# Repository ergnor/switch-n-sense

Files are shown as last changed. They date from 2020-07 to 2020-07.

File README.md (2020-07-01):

# Switch-N-Sense
This is a Kicad redesign of switch-n-sense pcb from LibreSolar project

## Design changes:

* Wire to board connector is replaced with cheaper alternative - Keystone 8197 (30A rating)
* MOSFET's footprint now is TDSON-8-1 for 5x6 mm SMD transistors 
* Pinout of connector to the BMS (IDC connector) is compatible with previous version of pcb
* C1,C2,C6 and C7 are changed to 0805(2012) size

## Current target

Current rating can be adjusted depending on chosen MOSFETs and sense resistors, but major limiting factor is connector (30A)

| MOSFET (2x) | Voltage | Maximum Current | Remark |
|---|---|---|---|
|NVMFS6H800NT1G | 48V | 30 A | connector limited |

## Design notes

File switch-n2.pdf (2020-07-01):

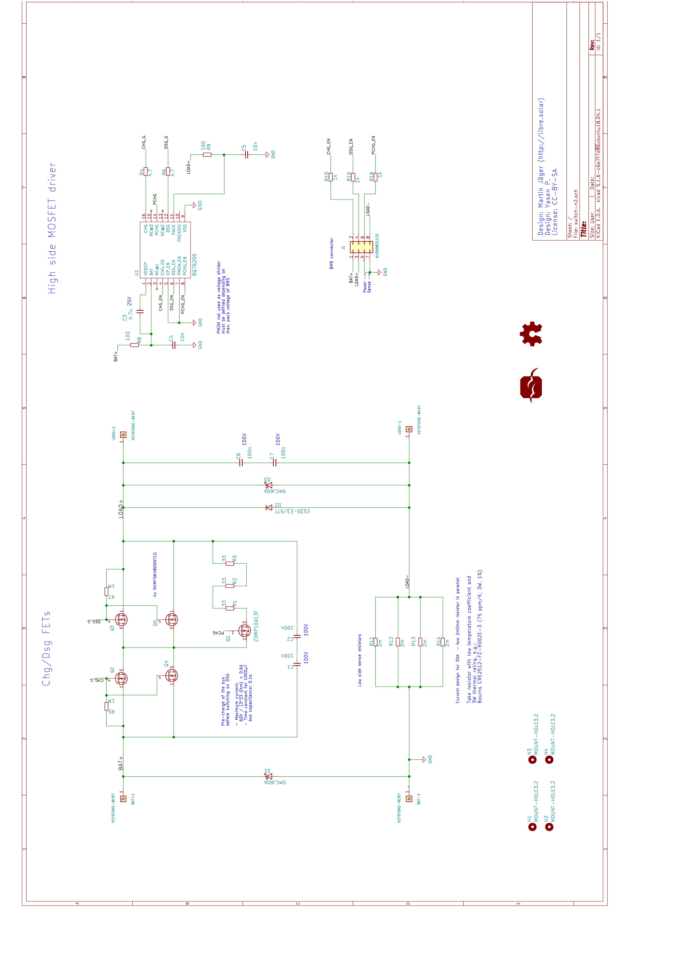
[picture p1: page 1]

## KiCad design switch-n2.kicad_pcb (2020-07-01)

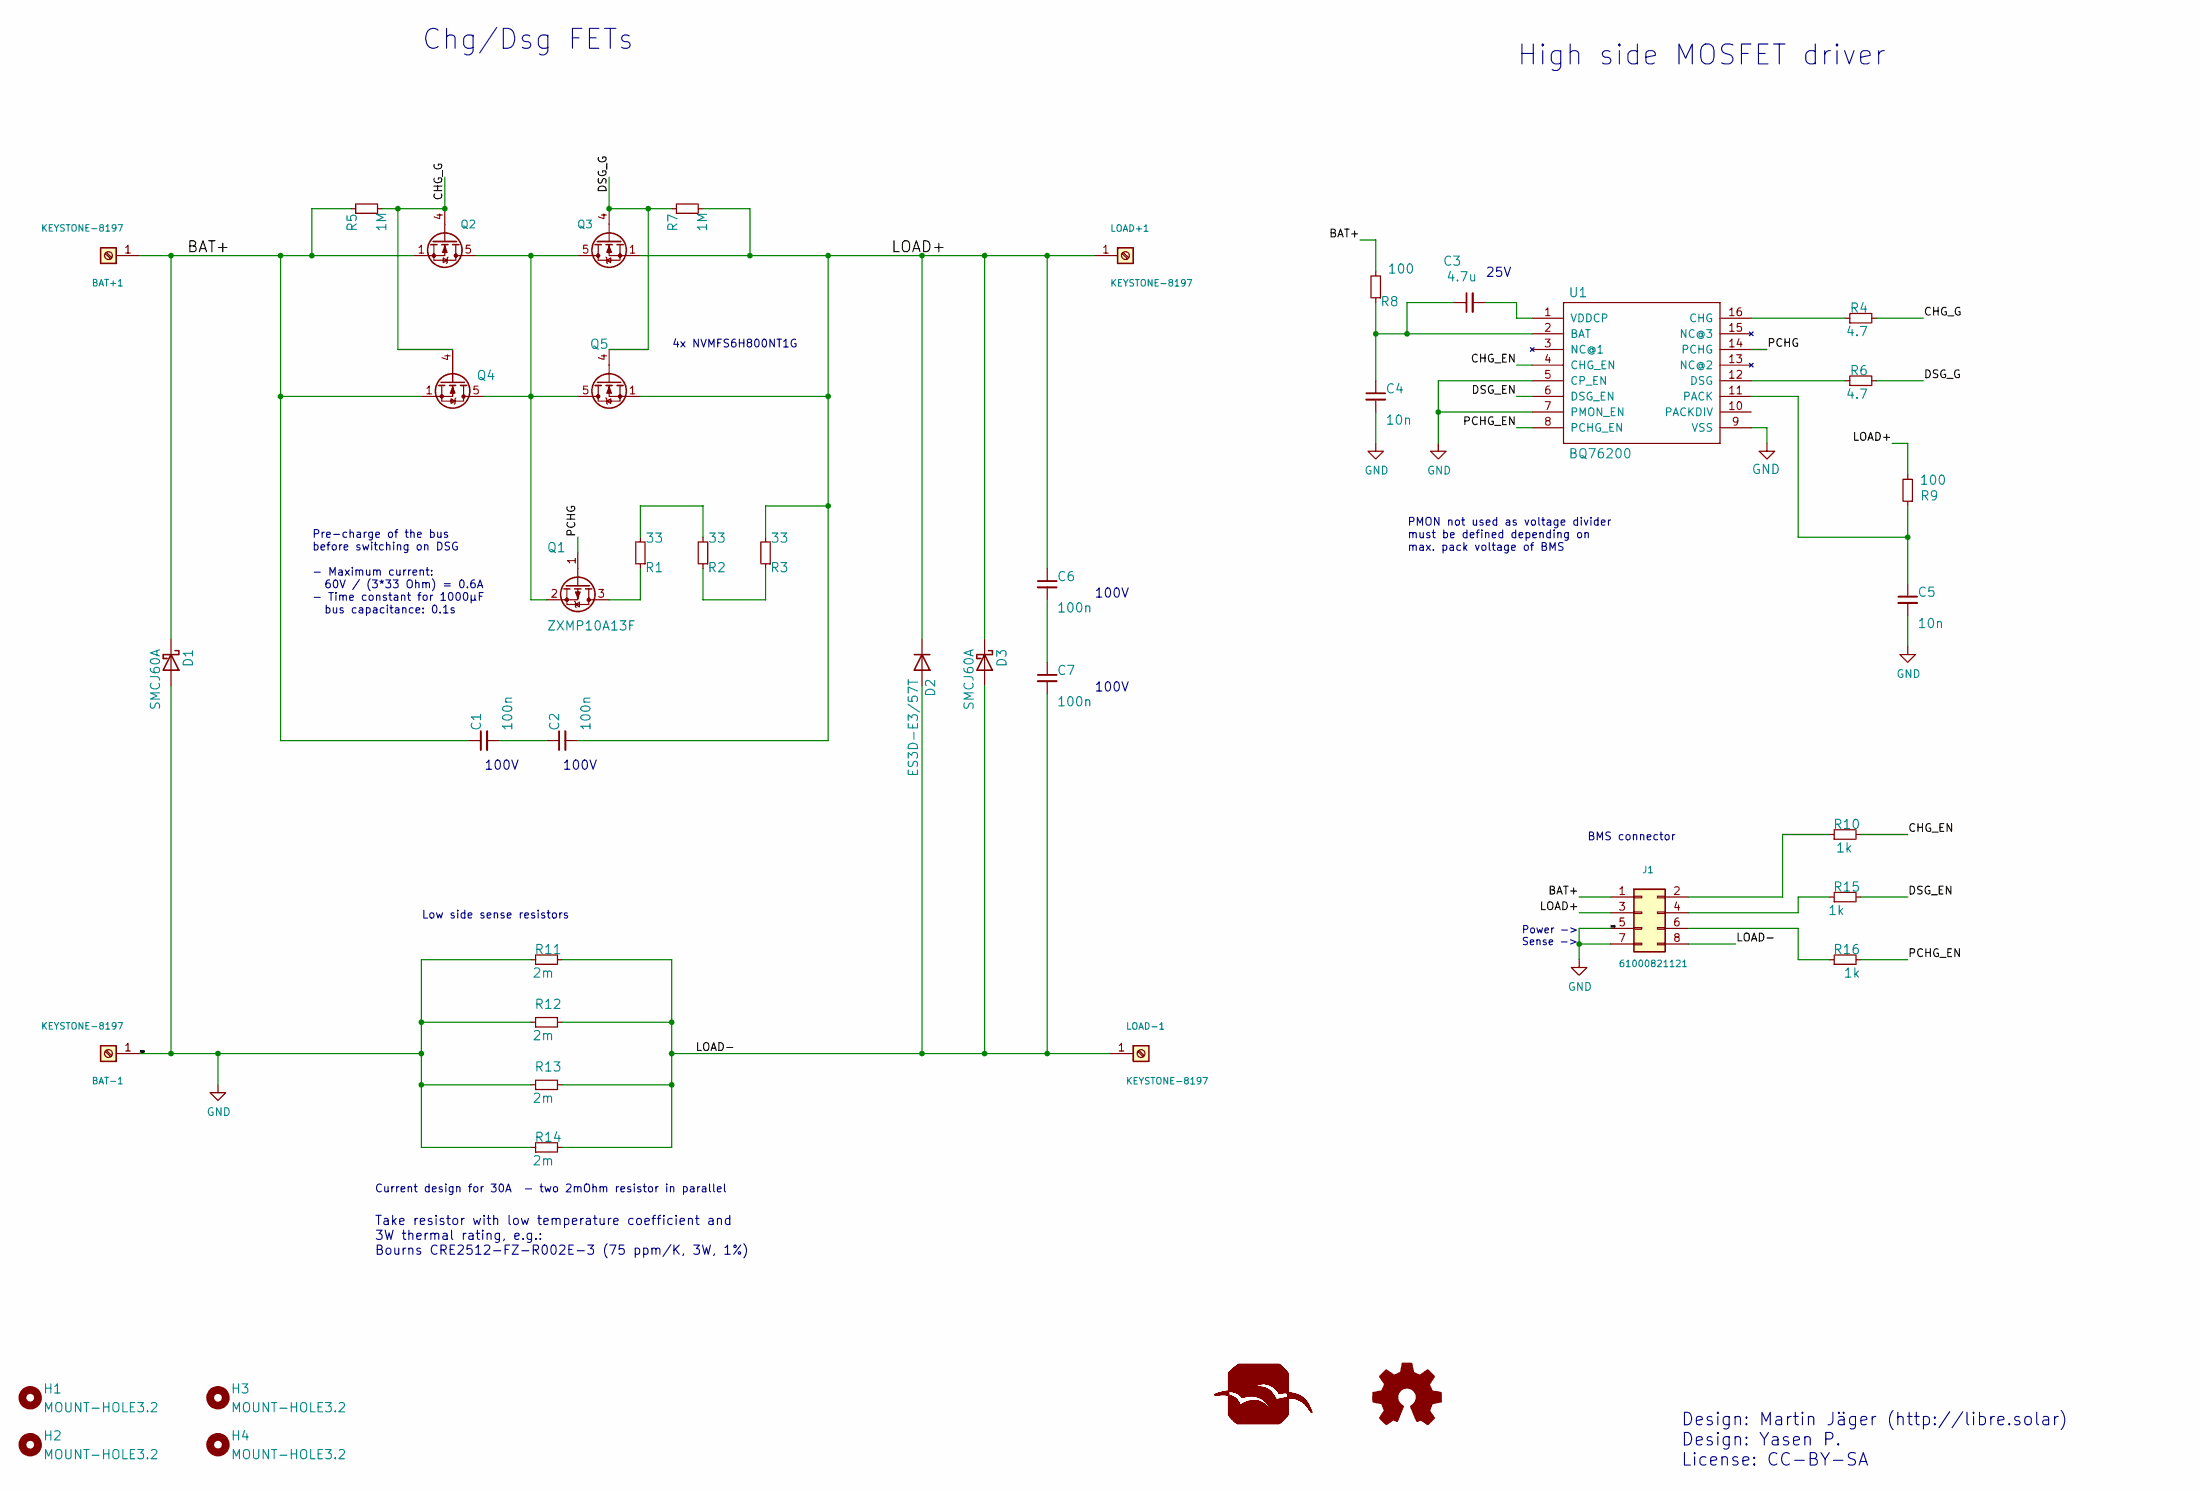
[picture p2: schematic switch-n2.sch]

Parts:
BAT+1: KEYSTONE-8197; 8197
BAT-1: KEYSTONE-8197; 8197
C1, C2, C6, C7: 100n; C_0805_2012Metric; MPN 0603B104K500CT
C3: 4.7u; C_0805_2012Metric; MPN 0603B104K500CT
C4, C5: 10n; C_0603_1608Metric; MPN GRM188R71H103KA01D.
D1, D3: SMCJ60A; D_SMC; MPN SMCJ75A
D2: ES3D-E3/57T; D_SMC; MPN ES3D-E3/57T.
H1, H2, H3, H4: MOUNT-HOLE3.2; MountingHole_3.2mm_M3_ISO14580_Pad
J1: 61000821121; PinHeader_2x04_P2.54mm_Vertical_SMD
LOAD+1: KEYSTONE-8197; 8197
LOAD-1: KEYSTONE-8197; 8197
N1: OSHW-LOGOM; OSHW-LOGO-M
Q1: ZXMP10A13F; SOT-23; MPN ZXMP10A13FTA
Q2, Q3, Q4, Q5: NVMFS6H800NT1G; TDSON-8-1
R1, R2, R3: 33; R_2010_5025Metric; MPN ASC2010-33RFT4
R4, R6: 4.7; R_0603_1608Metric; MPN ERJU06F1004V
R5, R7: 1M; R_0603_1608Metric; MPN ERJU06F1004V
R8, R9: 100; R_0603_1608Metric; MPN MCMR06X1001FTL
R10, R15, R16: 1k; R_0603_1608Metric; MPN ERJU06F1004V
R11, R12, R13, R14: 2m; R_2512_6332Metric
U1: BQ76200; TSSOP16
U$1: LIBRESOLAR_LOGO

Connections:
/BAT+: BAT+1.1, C1.1, D1.1 (K), J1.1, Q2.1 (S), Q2.2 (S), Q2.3 (S), Q4.1 (S), Q4.2 (S), Q4.3 (S), R5.1, R8.2
/CHG_EN: R10.2, U1.4 (CHG_EN)
/CHG_G: Q2.4 (G), Q4.4 (G), R4.2, R5.2
/DSG_EN: R15.2, U1.6 (DSG_EN)
/DSG_G: Q3.4 (G), Q5.4 (G), R6.2, R7.1
/LOAD+: C2.2, C6.1, D2.1 (K), D3.1 (K), J1.3, LOAD+1.1, Q3.1 (S), Q3.2 (S), Q3.3 (S), Q5.1 (S), Q5.2 (S), Q5.3 (S), R3.2, R7.2, R9.2
/LOAD-: C7.2, D2.2 (A), D3.2 (A), J1.8, LOAD-1.1, R11.2, R12.2, R13.2, R14.2
/PCHG: Q1.1 (G), U1.14 (PCHG)
/PCHG_EN: R16.2, U1.8 (PCHG_EN)
GND: BAT-1.1, C4.2, C5.2, D1.2 (A), J1.5, J1.7, R11.1, R12.1, R13.1, R14.1, U1.5 (CP_EN), U1.7 (PMON_EN), U1.9 (VSS)
unnamed: C1.2, C2.1
unnamed: C3.1, C4.1, R8.1, U1.2 (BAT)
unnamed: C3.2, U1.1 (VDDCP)
unnamed: C5.1, R9.1, U1.11 (PACK)
unnamed: C6.2, C7.1
unnamed: J1.2, R10.1
unnamed: J1.4, R15.1
unnamed: J1.6, R16.1
unnamed: Q1.2 (S), Q2.5 (D), Q3.5 (D), Q4.5 (D), Q5.5 (D)
unnamed: Q1.3 (D), R1.1
unnamed: R1.2, R2.2
unnamed: R2.1, R3.1
unnamed: R4.1, U1.16 (CHG)
unnamed: R6.1, U1.12 (DSG)

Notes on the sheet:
Pre-charge of the bus before switching on DSG - Maximum current: 60V / (3*33 Ohm) = 0.6A - Time constant for 1000µF bus capacitance: 0.1s
Chg/Dsg FETs
High side MOSFET driver
Design: Martin Jäger (http://libre.solar) Design: Yasen P. License: CC-BY-SA
4x NVMFS6H800NT1G
Take resistor with low temperature coefficient and 3W thermal rating, e.g.: Bourns CRE2512-FZ-R002E-3 (75 ppm/K, 3W, 1%)
Low side sense resistors
BMS connector
Power -> Sense ->
PMON not used as voltage divider must be defined depending on max. pack voltage of BMS
100V
25V
Current design for 30A - two 2mOhm resistor in parallel

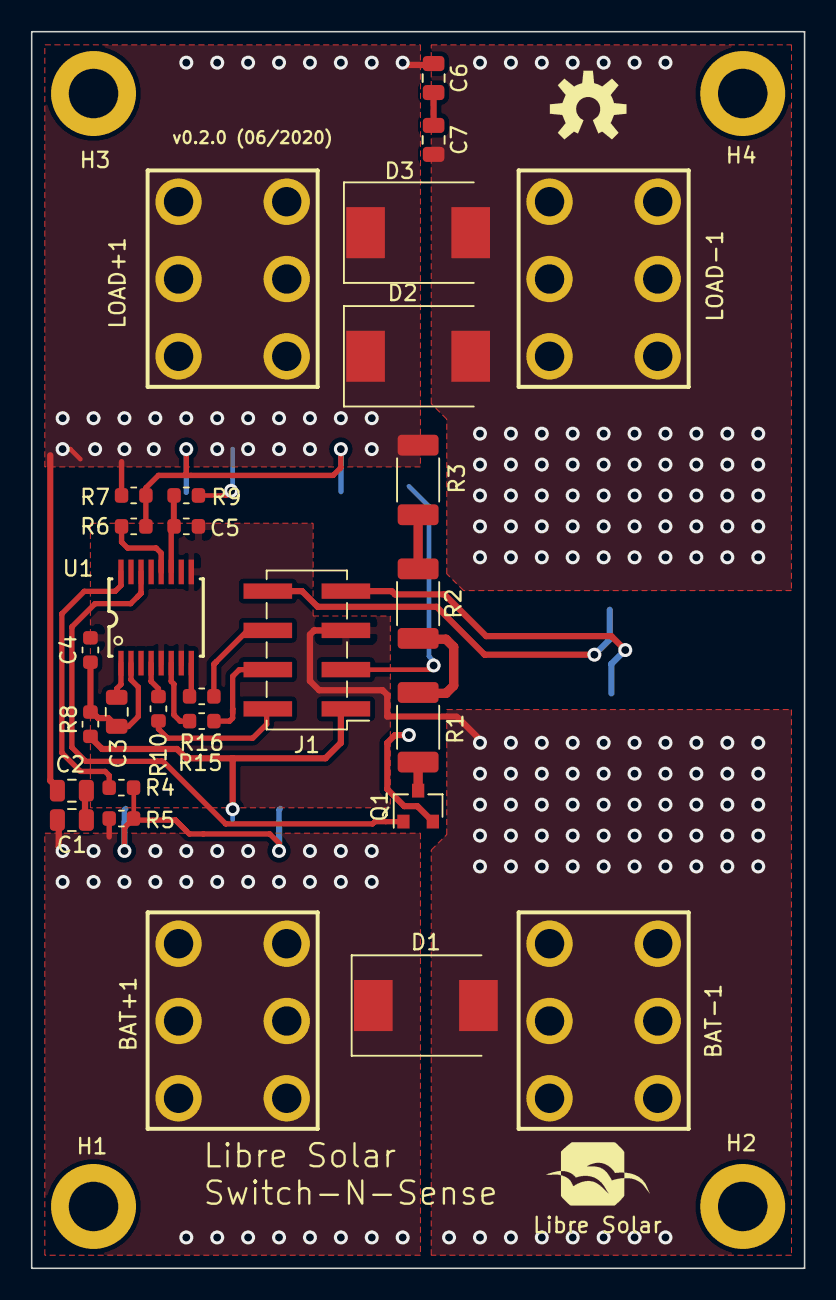
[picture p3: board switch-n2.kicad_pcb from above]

Board: 2 copper layers, 50.0 x 80.0 mm, 43 parts (0 on the bottom side), 24 nets.

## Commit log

2020-06-28 my snapshot
    [Switch-N-Sense.brd, Switch-N-Sense.sch, switch-n2.kicad_pcb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]
2020-06-30 Fixed some comments on schematic
    [switch-n2.kicad_pcb, switch-n2.sch]
2020-07-01 Clean up schematics and add pdf version
    [switch-n2.kicad_pcb, switch-n2.sch]
